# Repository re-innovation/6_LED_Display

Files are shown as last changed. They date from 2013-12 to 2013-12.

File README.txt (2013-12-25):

This is the github repository for a 6 digit 7 segment LED board.
The board is based upon an ATmega328 microcontroller programmed with the Arduino Uno bootloader.
This project has been started by Matt Little from Renewable Energy Innovation.
Contact:
www.re-innovation.co.uk
matt@re-innovation.co.uk

Overview:

This kit contains 6 x 0.56" 7 segment LED units, along with an AS1107 SPI LED driver and Arduino microcontroller.

see www.re-innovation.co.uk for more details

Files in the repository:
	
	Readme
	PCB files for KiCAD
	Example Arduino code

Modified:

To Do:

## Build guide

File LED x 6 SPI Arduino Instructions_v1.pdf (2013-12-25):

## Six Digit LED Display Unit

Date: | 24/12/13 | Version: | 1.0 | By: | Matt Little

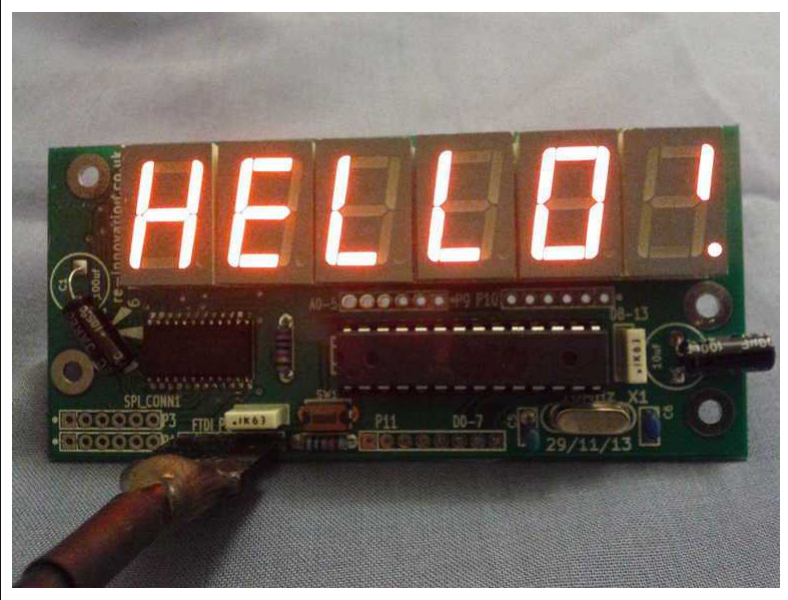
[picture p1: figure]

This LED display unit has a six digit 7-segment LED with decimal points.
It is controlled using the AS1107 8x8 LED SPI controller IC (identical in function to the MAX7219 IC). There is an ATMega328 on-board programmed with the Arduino bootloader. This connects to the SPI lines and so can be used to control the display.
All the various I/O from the Arduino are also available as connection points.
Test code is available to download.
A number of displays can be wired together with just one main controller unit.

Note: This requires an FTDI USB to serial 3V3 cable for programming.

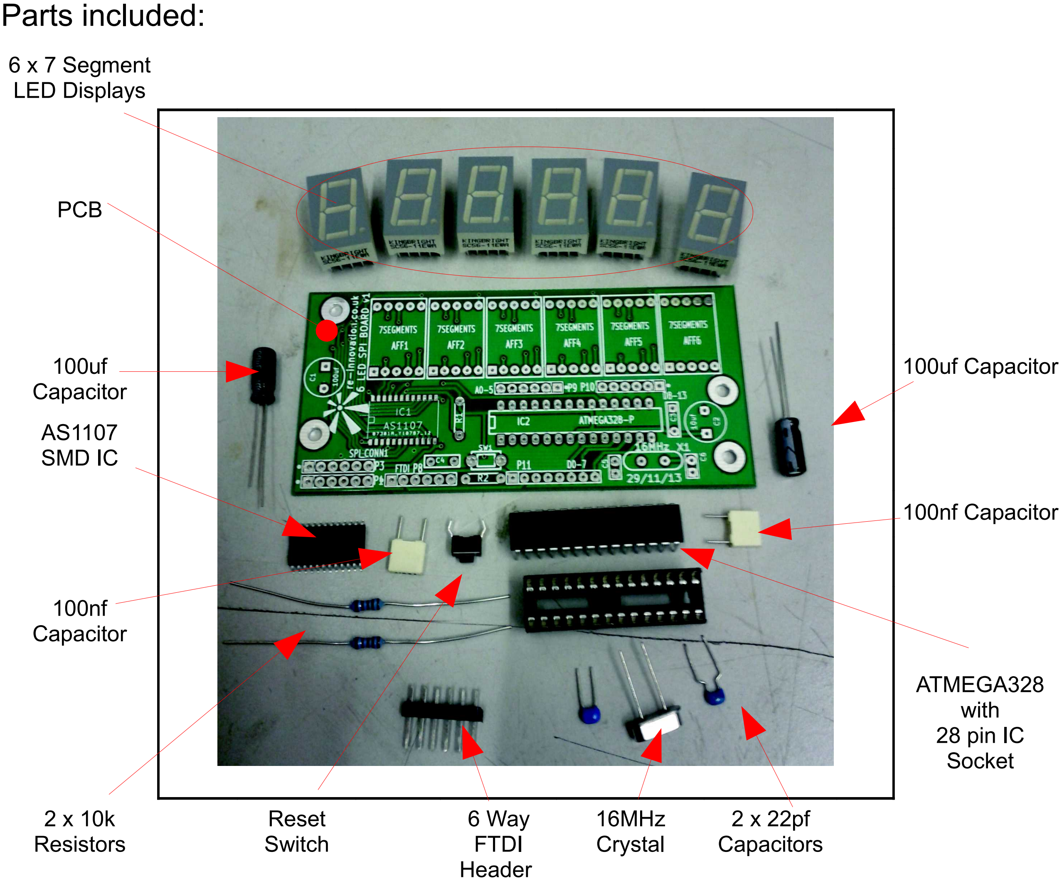
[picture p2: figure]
Parts included:; 6 x 7 Segment LED Displays; PCB; 100uf Capacitor; AS1107 SMD IC; 100nf Capacitor; ATMEGA328 with 28 pin IC Socket; 2 x 10k Resistors; Reset Switch; 6 Way FTDI Header; 16MHz Crystal; 2 x 22pf Capacitors

Parts list:

Reference | Description | Reference | Description
AFF1-6 | Battery holder | P4 | Mounting hole
C1 | 100uf electrolytic capacitor | P5 | Mounting hole
C2 | 100uf electrolytic capacitor | P6 | Mounting hole
C3 | 100nf | P8 | FTDI header (6-pin)
C4 | 100nf | P9 | Analog 0-5 pads
C5 | 22pF | P10 | Digital 8-13 pads
C6 | 22pF | P11 | Digital 0-7 pads
IC1 | AS1107 SPI LED Driver | R1 | 10k resistor
IC2 | ATMEGA328P-P – UNO boot-loader | R2 | 10k resistor
| 28 pin DIL socket | SW1 | Reset switch
P1 | SPI Input connector (not supplied) | X1 | 16MHz Crystal
P2 | Mounting hole | | PCB
P3 | SPI Output connector (not supplied)

You will also need (not supplied):
- a computer with the Arduino IDE installed
- a FTDI USB to serial cable with code: TTL-232R-3V3, such as this:

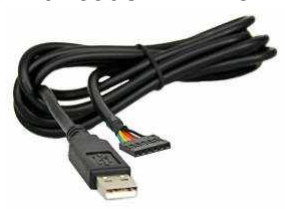
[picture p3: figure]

Available here (among other places): http://www.ftdichip.com/Products/Cables/USBTTLSerial.htm

Tools required:

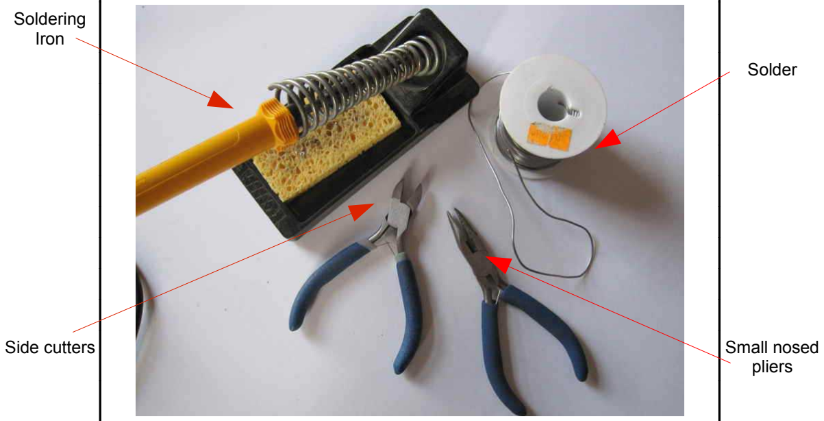
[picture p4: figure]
Side cutters; Small nosed; pliers

Soldering
Iron
Solder

Instructions:

Step: 1 Solder the SMD IC AS1107 Lets start with probably the most difficult soldering step. Its best to do this first, or the other components get in the way. Holding the IC with a pair of tweezers align over the solder pads.
Ensure the correct orientation – the dot on the IC will be at the end with the notch on the PCB.
Solder one pin on the corner of the IC. Ensure that the IC lines up with all the other pads. If you need to adjust it then heat the solder on the soldered pin and correct the IC.
Once it is aligned then you can solder the whole row of pins on the other side to the already soldered pin.
If you heat up the top pin and apply solder then drag down to the bottom pin, applying solder if required. This usually will solder all the pins. You may need to remove any excess solder using some solder wick.
Leave this to cool for a couple of seconds. Then use the same technique for the un-soldered side.

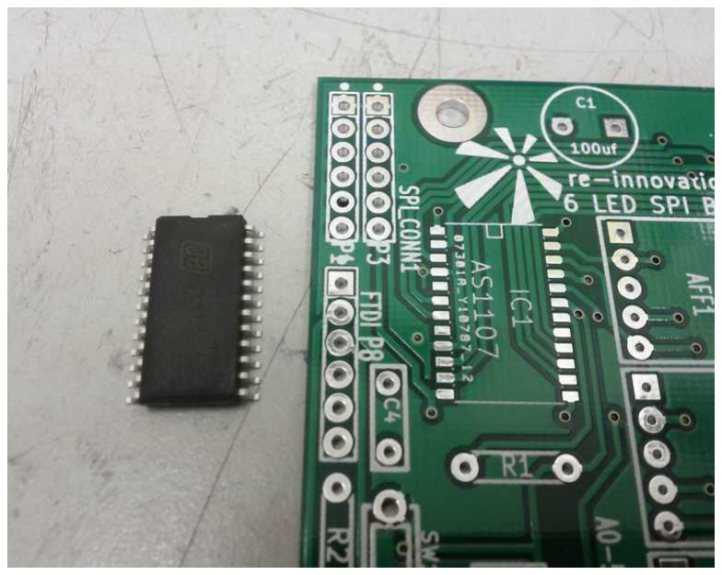
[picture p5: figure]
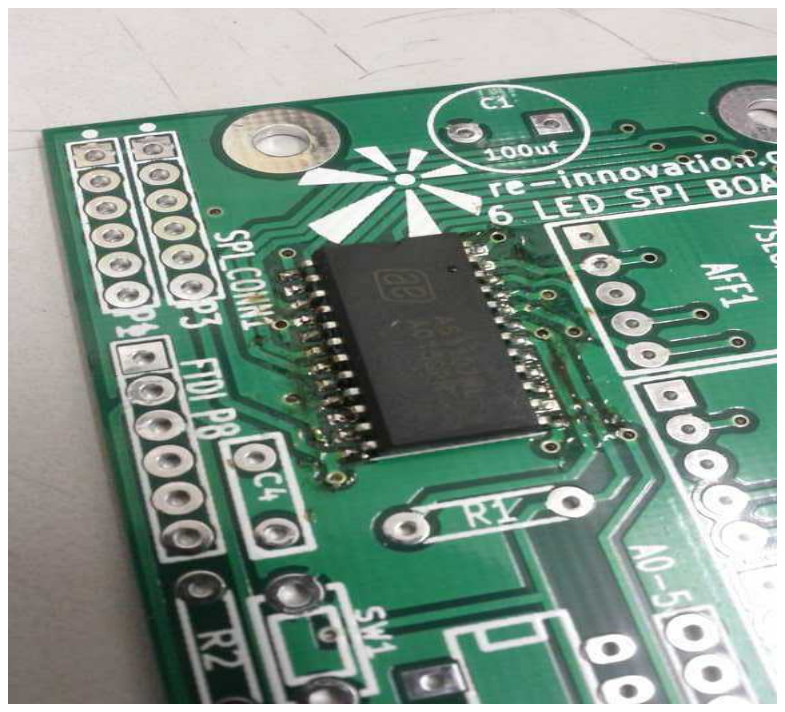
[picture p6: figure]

Step: 2 | Solder the FTDI programming header pins
| A 6 way header pin is used to program and interface to the micro-controller. This is soldered into port P8 FTDI.

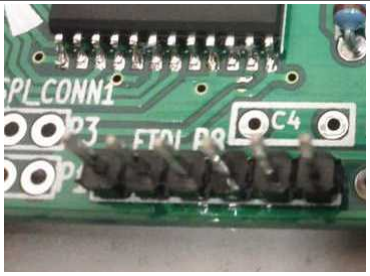
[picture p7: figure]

Step: 3 | Solder the IC socket
Check the orientation. The notch on the IC socket should align with the white notch drawn on the PCB. Note: If you would like the LED units to be places flush against a surface, then do not use the IC socket – instead solder in the ATmega328 directly (but ensure it is in the correct orientation).
Step: 4 | Solder the resistors

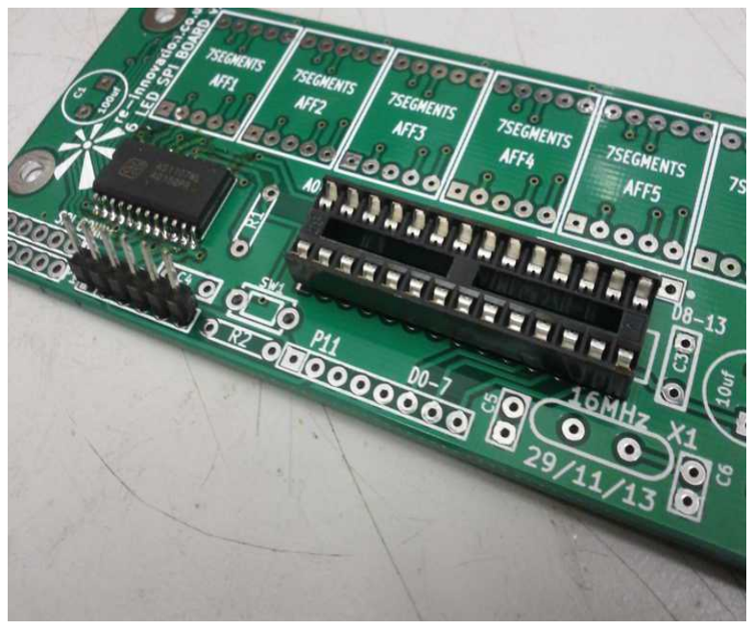
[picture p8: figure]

| Identify all the resistors. You will have:
Quantity | Value | Part Reference
2 | 10k | R1,R2

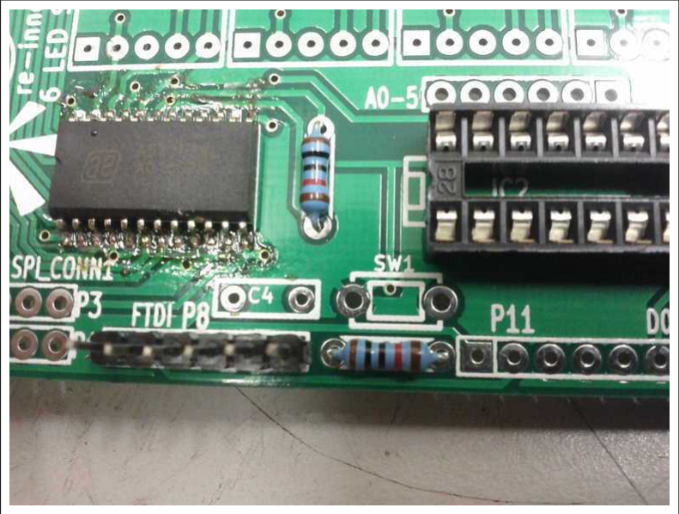
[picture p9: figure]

Use the identify chart at the end of these instructions or a multimeter.
Solder into the relevant places.
Their orientation does not matter.

Step: 5 | Solder the capacitors
| Identify and then solder in the capacitors.
Quantity | Value | Reference | Photo
2 | 100uf | C1, C2

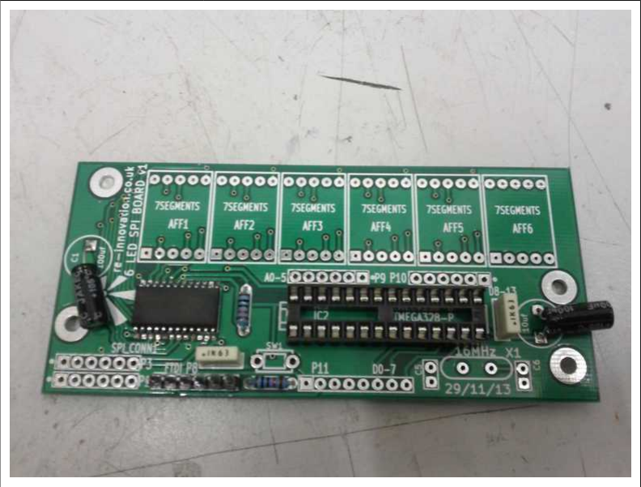
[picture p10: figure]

2 | 100nf | C3, C4

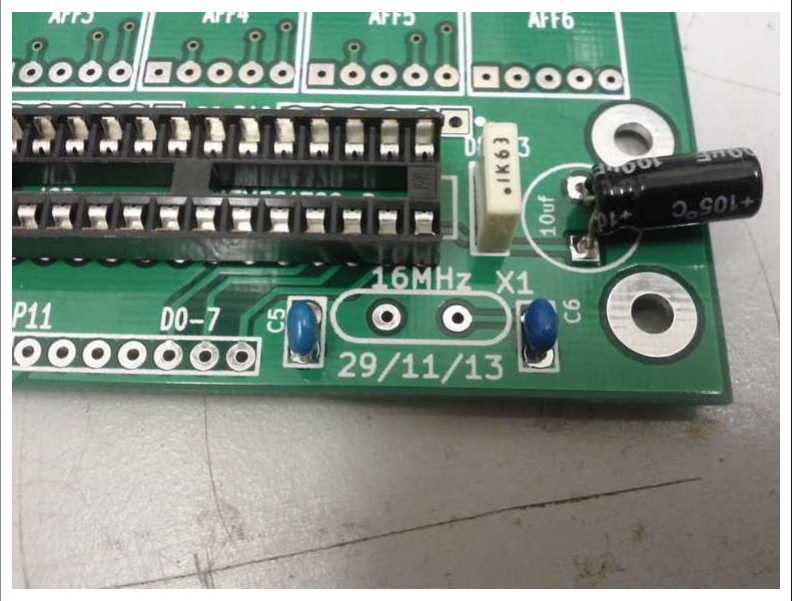
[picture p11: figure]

2 | 22pf | C4, C5 | (Blue or Brown)

Capacitors C3,C4,C5,C6 can be installed in either direction.
Check the orientation on capacitors C1,C2. The white line on the side signifies negative side. The round pad on the PCB signifies negative. The longer lead signifies positive. The square pad on the PCB is positive.
Step: 7 | Solder in reset switch
Solder in the two-pin reset switch.
Step: 8 | Solder the crystal

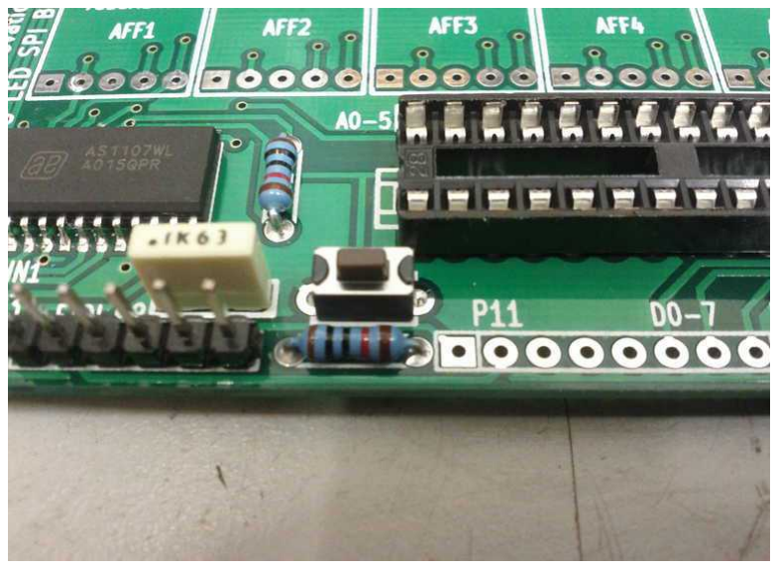
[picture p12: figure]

| Solder in the crystal. Orientation does not matter.

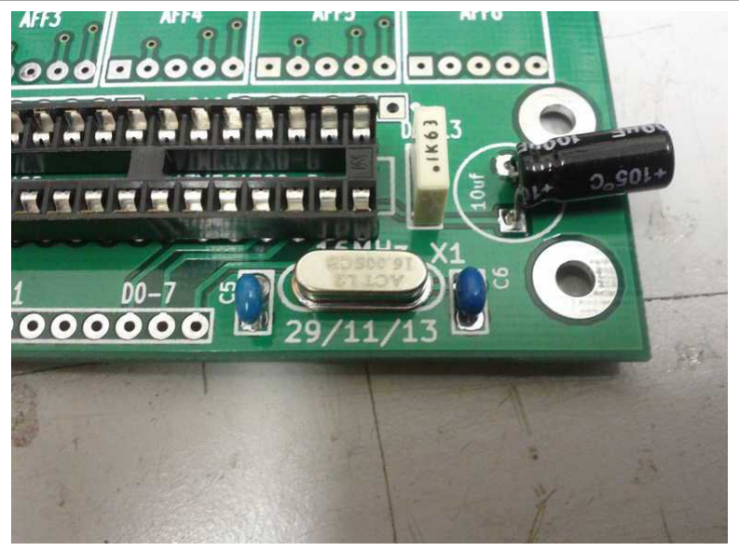
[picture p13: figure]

Step: 9 | Solder the 6 x 7 segment LED units Solder in the LED units. Ensure that they are in the correct orientation, with the decimal points all towards the ICs.

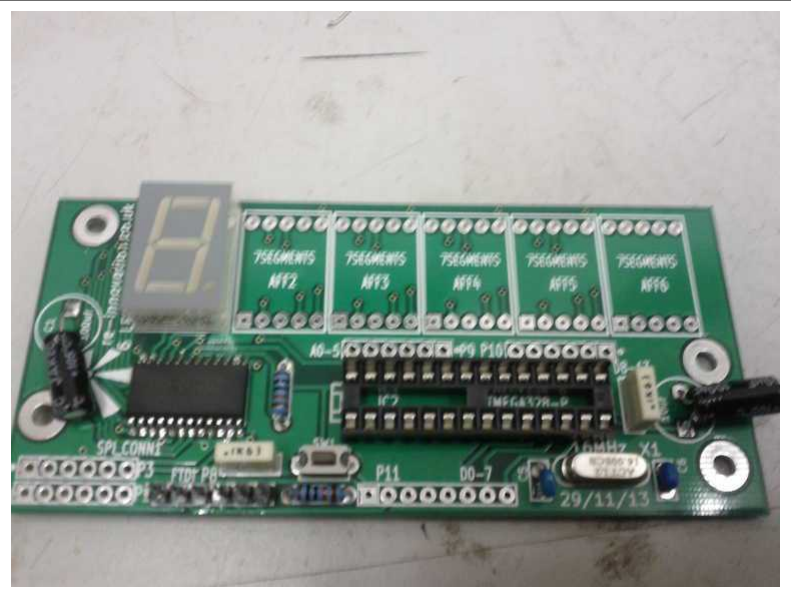
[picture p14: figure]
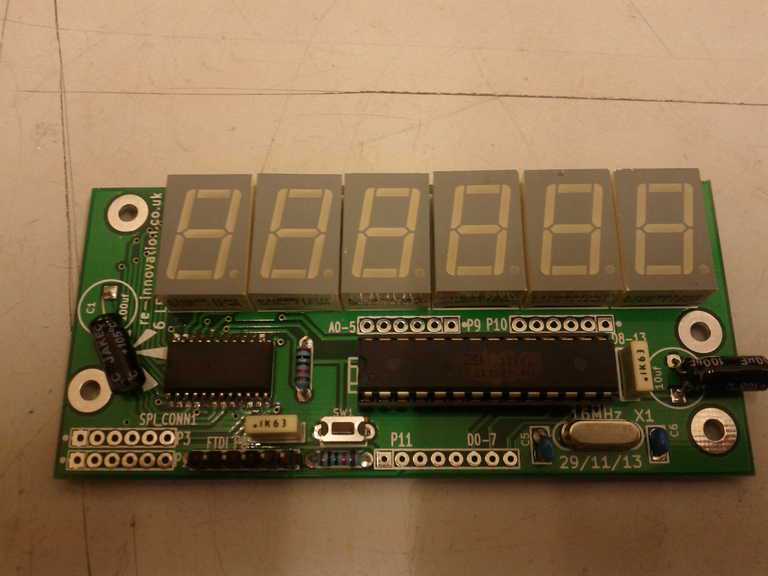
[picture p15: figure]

Step: 10 | Insert ATmega328 IC
Ensure it is inserted with the notch in the correct orientation, matching the notch on the IC socket and the PCB silkscreen.
Step: 11 | Build is finished!
Have a nice cup of tea.

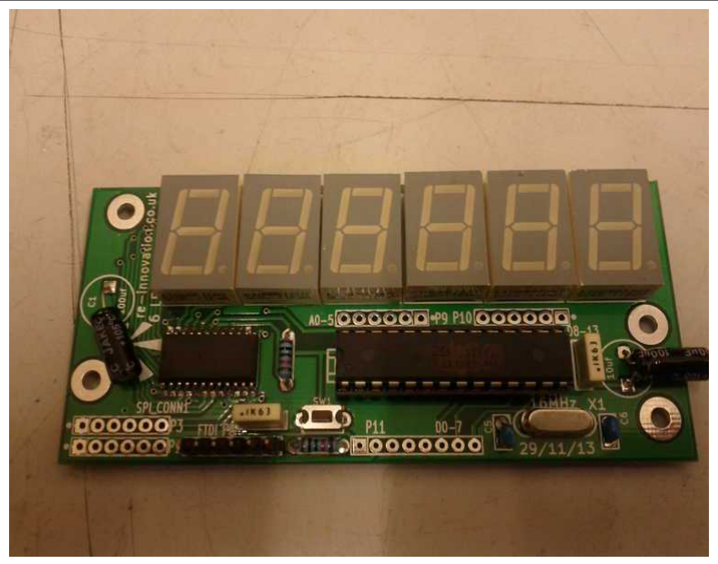
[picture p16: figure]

Once the device is constructed, the next step is check it powers up OK and then to program the device with test code.

Step: 12 | Check device powers up
| Plug in an FTDI cable from a computer to the FTDI programming header. The dot on the header silkscreen is the reset side (the other end is the black, negative, line which goes towards the resistor and reset switch). You should see the display read the test message. If not: • Test with a multimeter set to DC volts. • Do you have 5V between pins 7 and 8 of the ATMEGA328P-P? • If not, then re-check your soldering for short circuits. Also check the ICs and LED units are inserted in the correct orientation.

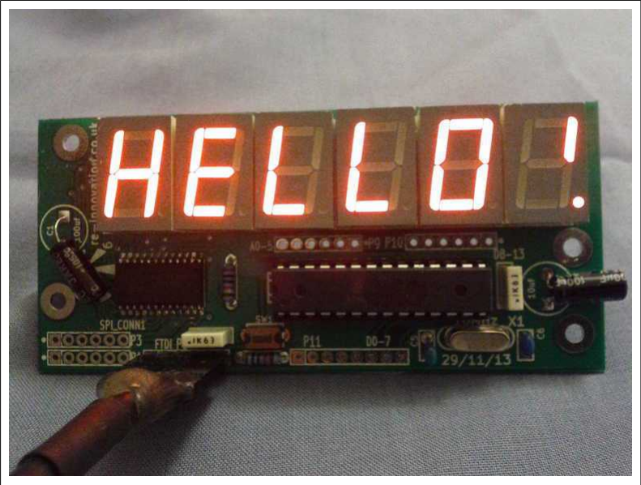
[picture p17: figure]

Step: 18 | Upload new code from a computer (Note: These instructions assume the user has some knowledge of the Arduino IDE environment and uploading code – if not please check arduino.cc for numerous examples)

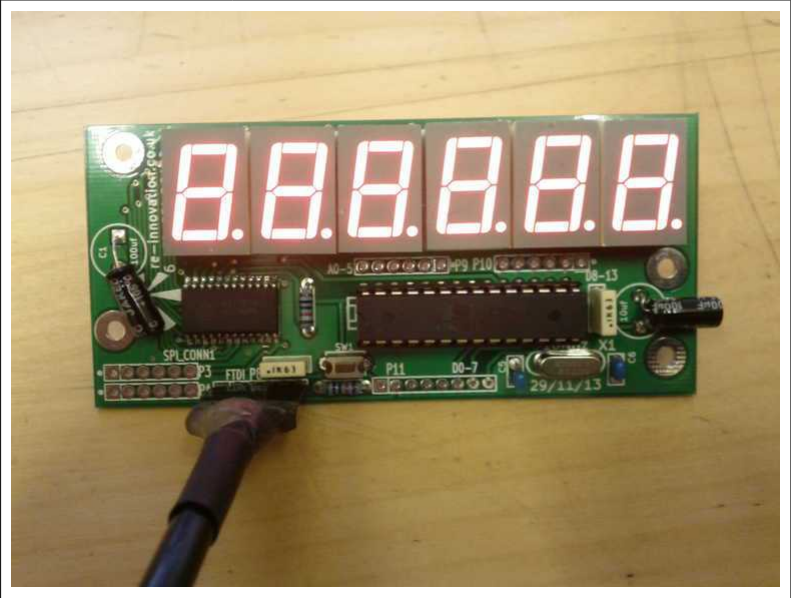
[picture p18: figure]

| If the unit has powered up OK then you can upload new code.
| This requires: • A computer running the Arduino IDE • An FTDI USB to serial lead • The test code • The LEDControl libraries

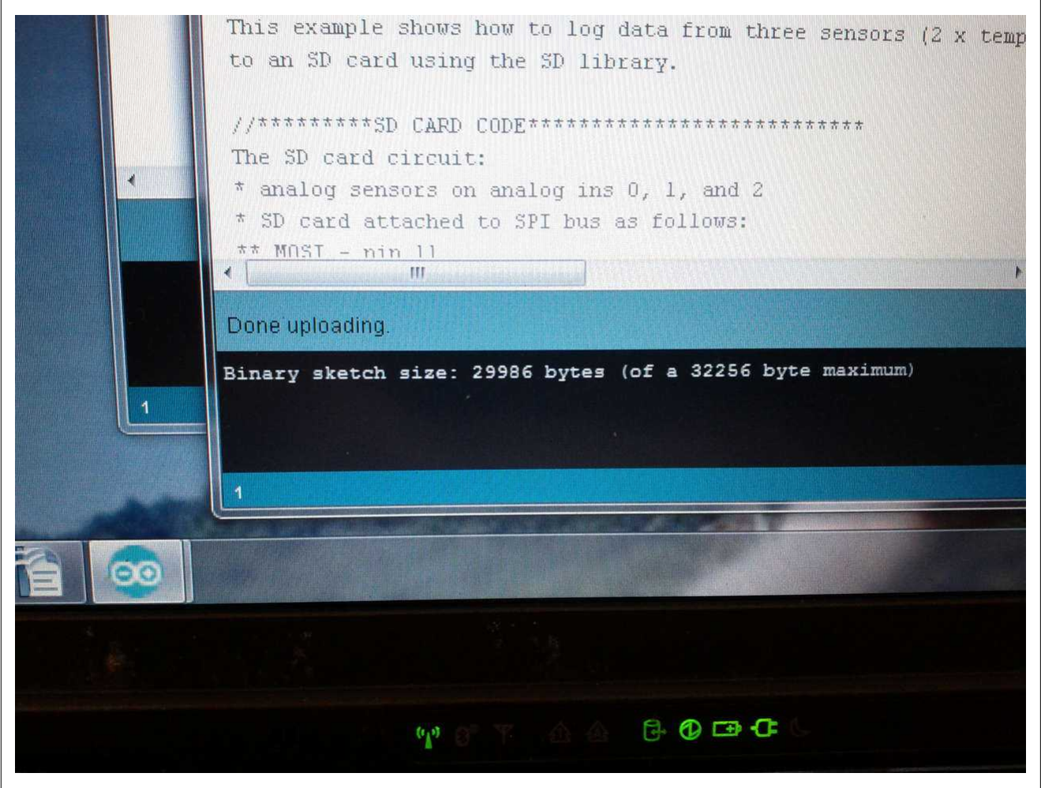
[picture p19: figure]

1. Check that the FTDI cable works.
2. Download the test code from:
| www.re-innovation.co.uk. Save this to your Arduino sketch book.
3. Download the LEDControl files from:
| http://playground.arduino.cc/Main/LedControl Save this to your Arduino sketch book, under libraries.
4. Open the Arduino IDE. This was written for
| IDE 1.0.5.
5. Open the test sketch.
6. Ensure that the sketch compiles with no
| errors.
7. Do NOT use any external power to the
| board. Power will be supplied via the FTDI cable.
8. Plug in the FTDI cable to you board. Ensure
| that the BLACK cable goes at the end towards the resistor. The GREEN cable

will go towards the dot.
9. Upload code to the arduino. It uses the UNO boot-loader. It should say 'Done Uploading'

Contact details:
This kit has been designed and produced by: Renewable Energy Innovation. info@re-innovation.co.uk
www.re-innovation.co.uk
Hopkinson Gallery
21 Station Street
Nottingham
NG7 6PD

We would like you to be happy with this kit. If you are not happy for any reason then please contact us and we can help to sort it out. Please email info@re-innovation.co.uk with any questions or comments.
If any parts are missing from your kit then please email info@re-innovation.co.uk with details, including where the kit was purchased.

More technical information can be found via www.re-innovation.co.uk.

Useful Information:
Resistor colour codes:

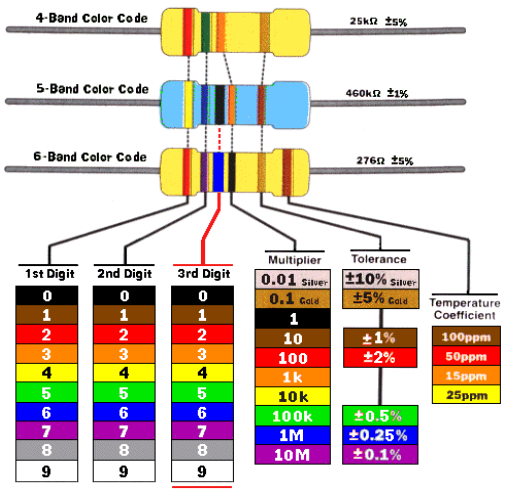
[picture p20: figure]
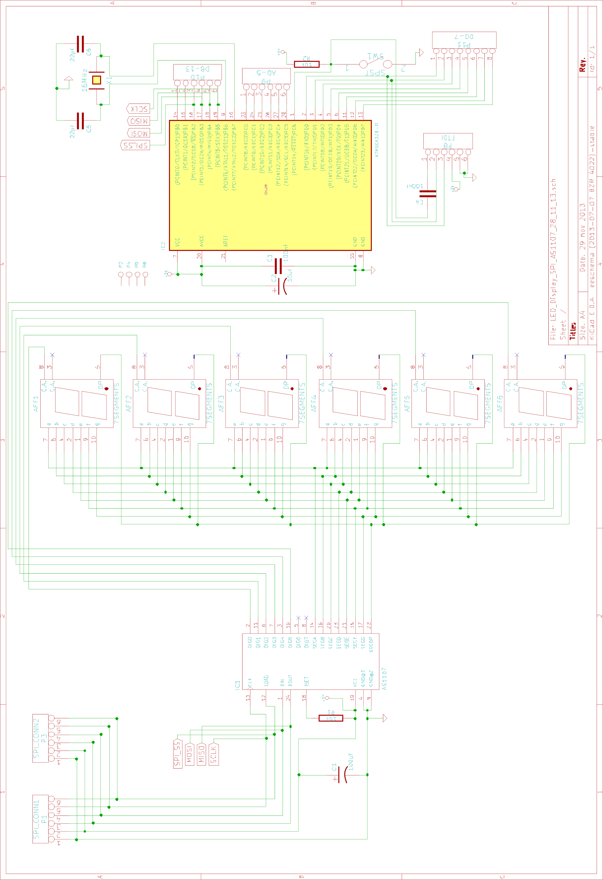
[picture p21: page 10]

Circuit schematic:

PCB overview:

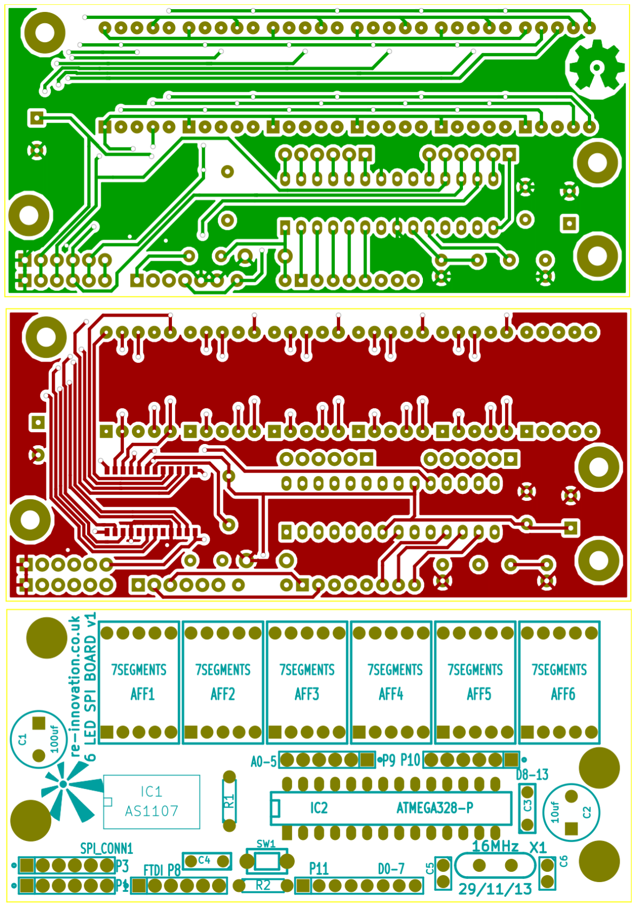
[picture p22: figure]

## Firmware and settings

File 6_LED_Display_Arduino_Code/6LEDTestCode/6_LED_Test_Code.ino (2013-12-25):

/********************************************************
/****** 6 x LED Unit with Controller ********************
/****** by Matt Little **********************************
/****** Date: 19/12/13 **********************************
/****** info@re-innovation.co.uk ************************
/****** www.re-innovation.co.uk *************************
/********************************************************

Utilising example code from:
http://playground.arduino.cc/Main/LedControl

You will have to download that library and install before using this code.

This test code will show you how to:
Display numbers
Display simple text (only a few characters available)
Display scrolling numbers/text
Fade the display up and down

The display uses an AS11007 8 x 7 segment LED driver.
There are 6 digits available (LHS: 0-5 :RHS).

see www.re-innovation.co.uk for more details
 
*/


//We always have to include the library
#include "LedControl.h"

/*
 Now we need a LedControl to work with.
 pin 13 is connected to the DataIn 
 pin 11 is connected to the CLK 
 pin 10 is connected to LOAD
 LedControl(MOSI,CLK,~CS,Number of units)
 
 */
LedControl lc=LedControl(11,13,10,1);

/* we always wait a bit between updates of the display */
unsigned long delaytime=250;


// This string is comprised of binary numbers which make digits.
// The 7 seg display comprises:
//
//  --a--
// f     b
// |     |
//  --g--
// e     c
// |     |
//  --d--   DP
//
// Where the binary number is: DP a b c d e f g
// This code says "7 SEg tESt HEllO !" 
char testString[30] = {
B00000000,B00000000,B00000000,B00000000,B00000000,B01110000,
B00000000,B01011011,B01001111,B01111011,
B00000000,B00001111,B01001111,B01011011,B00001111,B00000000,
B00110111,B01001111,B00001110,B00001110,B01111110,B10100000,B10100000,
B00000000,B00000000,B00000000,B00000000,B00000000
};

void setup() {
  // initialize the digital pin as an output.
  pinMode(10, OUTPUT);  
  digitalWrite(10, LOW);   // This is the LOAD or ~CS (chip select) line
  
  /*
   The MAX72XX/AS11007 is in power-saving mode on startup,
   we have to do a wakeup call
   */
  lc.shutdown(0,false);
  /* Set the brightness to a medium values */
  lc.setIntensity(0,8);
  /* and clear the display */
  lc.clearDisplay(0);
}

void loop() { 
  
  // Scroll some text on the disply:
  scrollTestOn7Segment();

  // Fade in?out a message:
  fadeDisplay();

  // Count up from 0 to 999
  countNumbers();
  
  delay(1000);  // Pause for a short time
  
}


/*
 This method will display the characters for the
 words "7 SEG TEST HELLO! " one after the other on digit 0. 
 */
void scrollTestOn7Segment() {
  
  for(int i=0;i<25;i++)
  {
    lc.setRow(0,0,testString[i]);
    lc.setRow(0,1,testString[i+1]);
    lc.setRow(0,2,testString[i+2]);
    lc.setRow(0,3,testString[i+3]);
    lc.setRow(0,4,testString[i+4]);
    lc.setRow(0,5,testString[i+5]);
    delay(delaytime);
  }
}

// This function will print a number (from -999 to 999)
// onto digits 2,3,4,5
void printNumber(int v) {
    int ones;
    int tens;
    int hundreds;
    boolean negative = false;	

    if(v < -999 || v > 999) 
    {
       return;
    }
    if(v<0) 
    {
        negative=true;
        v=v*-1;
    }
    
    ones=v%10;
    v=v/10;
    tens=v%10;
    v=v/10;
    hundreds=v;			
    if(negative) {
       //print character '-' in the leftmost column	
       lc.setChar(0,2,'-',false);
    }
    else {
       //print a blank in the sign column
       lc.setChar(0,2,' ',false);
    }
    //Now print the number digit by digit
    lc.setDigit(0,3,(byte)hundreds,false);
    lc.setDigit(0,4,(byte)tens,false);
    lc.setDigit(0,5,(byte)ones,false);
}


/*
 This method will count up very fast from 
  0-1000 on digits 2-5.
 */
void countNumbers() {
  
  for(int i=0;i<=999;i++)
  {
    printNumber(i);
    delay(10);
  }
  
}


/*
 This method will put some data on the display and fade 
 up and down.
 */
void fadeDisplay() {
    lc.setRow(0,0,testString[16]);
    lc.setRow(0,1,testString[17]);
    lc.setRow(0,2,testString[18]);
    lc.setRow(0,3,testString[19]);
    lc.setRow(0,4,testString[20]);
    lc.setRow(0,5,testString[21]);
    
    for(int i=0;i<16;i++)
    {
      lc.setIntensity(0,i);
      delay(delaytime);
    }    
    
    for(int i=0;i<16;i++)
    {
      lc.setIntensity(0,15-i);
      delay(delaytime);
    }
    // Set intensity back to a medium value
    lc.setIntensity(0,8);    
    /* and clear the display */
    lc.clearDisplay(0);
}
